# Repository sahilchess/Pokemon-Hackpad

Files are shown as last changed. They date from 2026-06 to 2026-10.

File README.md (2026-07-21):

# Pokemon Hackpad!
<!---
![picture of pokemon hackpad](assets/photo.png)
picture to come!
-->

[CAD](https://cad.onshape.com/documents/8d1a80880a531cce319d6767/w/a72820820093b362710dff01/e/ab70c80eedf68ce27917fcfd)

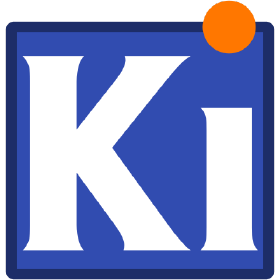
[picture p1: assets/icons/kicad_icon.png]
kicad
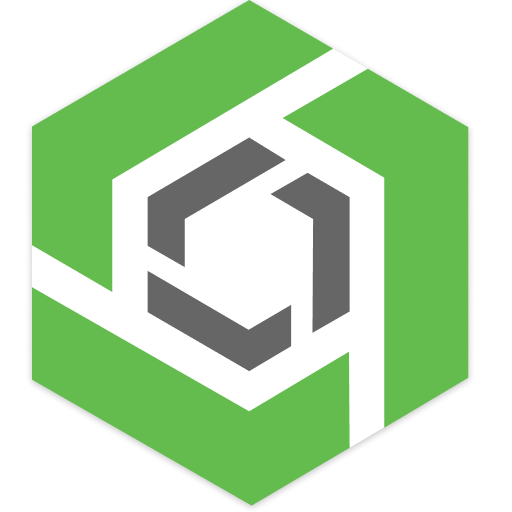
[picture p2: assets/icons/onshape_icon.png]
onshape
  things used (https://skillicons.dev)

Pokemon Hackpad is a 5 key macropad with a rotary switch/encoder, and 4 SK6812 MINI E RGB LEDs. It uses KMK/QMK(wip) firmware. I designed this as my own macropad through [hackpad](https://hackclub.hackpad.com), a Hack Club program where you learn to design your own macropad and get it for free

## Features:
- An EC11 rotary encoder, controls volume, click to mute
- 3 SK6812 MINI E RGB LEDs, swirl and static modes
- 5 Cherry MX style keys
- 128x32 OLED Screen
- Pokemon themed design

## CAD Model:
Here is the case, made in onshape. I used onshape because Fusion basically blew my computer up. 





## PCB
Here's the PCB, made in KiCad.




## Firmware Overview
This hackpad uses [KMK](https://github.com/KMKfw/kmk_firmware) firmware for everything.
- the rotary encoder changes volume, press to mute
- the 5 regular keys are copy, paste, undo, redo
- rgb leds swirl by default, static color available

## BOM (more elaborate BOM [here](http://github.com/sahilchess/Pokemon-Hackpad/blob/main/production/BOM.md)):
Here should be everything you need to make this amazing hackpad
- 5x Cherry MX Switches
- 5x DSA Keycaps
- 6x 1N4148 DO-35 Diodes
- 3x SK6812 MINI E RGB LEDs
- 1x EC11 Rotary Encoder
- 1x 0.91 inch OLED display
- 4x M3x16mm screws
- 4x M3x5mx4mm heatset inserts
- 1x XIAO RP2040



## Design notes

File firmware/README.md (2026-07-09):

# Firmware

This hackpad runs KMK firmware on the XIAO RP2040

## Files

main.py the whole firmware, matrix, encoder, rgb, and oled setup

## Pinout

col0 GP26, col1 GP27, col2 GP28
row0 GP3, row1 GP4
encoder a GP2, encoder b GP1, encoder click is wired into the matrix at row0 col2
rgb data GP29, 3x SK6812 MINI E leds
oled sda GP6, scl GP7, 0.91in 128x32 SSD1306

## Keymap

copy  paste  mute/encoder click
undo  select all  redo

encoder rotate changes volume, rgb boots into swirl mode, oled shows a static text screen

## Setup

install CircuitPython on the XIAO RP2040
copy the kmk library folder from kmk_firmware onto CIRCUITPY
copy main.py onto CIRCUITPY, it runs automatically on boot

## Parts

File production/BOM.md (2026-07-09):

# Pokemon Hackpad - Bill of Materials
Welcome to the **Bill of Materials (BOM)** for the Pokemon Hackpad.

| **Component** | **Qty** | **Notes** |
|---|---|---|
| **XIAO RP2040** | 1 | |
| **SK6812 Mini LEDs** | 4 | |
| **Rotary Encoder** | 1 | |
| **Cherry MX Switches** | 5 | |
| **Diodes** | 6 | |
| **OLED Display** | 1 | |

Others:

| **Component** | **Qty** | **Notes** |
|---|---|---|
| **1U Keycaps** | 5 | |
| **KMK Firmware** | 1 | |
| **PCB** | 5 | ordered from JLCPCB, Pokemon-Hackpad_Y29, $7.12 total, est arrival 2026-06-22 |

## Kit Provided

| **Part** | **Qty Provided** | **Qty Needed** |
|---|---|---|
| Seeed XIAO RP2040 microcontroller  | 1 | 1 |
| 1N4148 through hole diodes | 20 | 6 |
| MX style mechanical switches | 16 | 5 |
| EC11 rotary encoders (20mm D shaft)| 2 | 1 |
| SK6812 MINI E RGB LEDs | 20 | 4 |
| Blank DSA keycaps | 16 | 5 |
| M3x16mm screws | 6 | 4 |
| M3x5x4mm heatset inserts | 6 | 4 |
| OLED | 1 | 1 |

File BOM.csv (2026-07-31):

item | description | cost
hackpad kit | all parts needed to build hackpad | included
soldering iron grant | card grant to buy a soldering iron | $18
pcb grant | card grant to buy pcb | $15

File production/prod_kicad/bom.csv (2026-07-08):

Designator | Footprint | Quantity | Value | LCSC Part #
D1, D2, D3, D4, D5, D6 | D_DO-35_SOD27_P7.62mm_Horizontal | 6 | Diode
D10, D8, D9 | LED_SK6812MINI-E_3.2x2.8mm_P1.5mm_ReverseMount | 3 | SK6812MINI-E
J1 | SSD1306-0.91-OLED-4pin-128x32 | 1 | OLED_DISPLAY
S1, S2, S3, S4, S5 | SW_Cherry_MX_1.00u_PCB | 5 | Keyswitch
SW1 | RotaryEncoder_Alps_EC11E-Switch_Vertical_H20mm | 1 | RotaryEncoder_Switch
U1 | XIAO-Generic-Hybrid-14P-2.54-21X17.8MM | 1 | MOUDLE-SEEEDUINO-XIAO

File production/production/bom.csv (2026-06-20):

Designator | Footprint | Quantity | Value | LCSC Part #
D1, D2, D3, D4, D5, D6 | D_DO-35_SOD27_P7.62mm_Horizontal | 6 | Diode
D10, D7, D8, D9 | LED_SK6812MINI-E_3.2x2.8mm_P1.5mm_ReverseMount | 4 | SK6812MINI-E
S1, S2, S3, S4, S5 | SW_Cherry_MX_1.00u_PCB | 5 | Keyswitch
SW1 | RotaryEncoder_Alps_EC11E-Switch_Vertical_H20mm | 1 | RotaryEncoder_Switch
U1 | XIAO-Generic-Hybrid-14P-2.54-21X17.8MM | 1 | MOUDLE-SEEEDUINO-XIAO

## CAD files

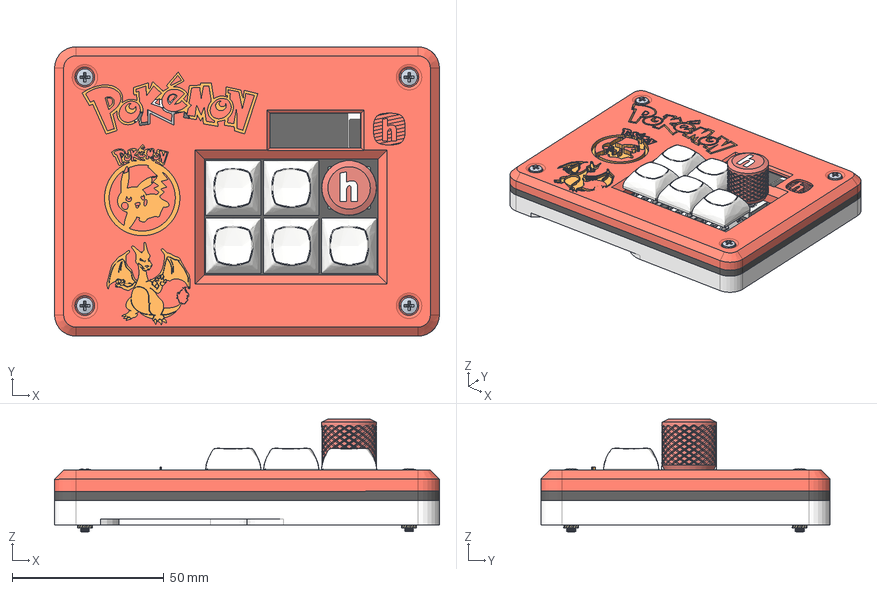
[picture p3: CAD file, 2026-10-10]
CAD/main.step
126.6 x 95.2 x 37.1 mm
Pokemon Hackpad-unsaved-export-4L2n7u_copper x 47
Pin2__Vaciado1 x 5
brep_1 x 4
DSA 1u v2__DSA 1u v2_1 x 5
H:1__Body1
Pin Header 4 x 1 TH 2.54mm Pitch:1__Твердое тело2
id55 x 4
00 Bottom Case
00 Top Case
Top__Redondeo7 x 5
Pin1__Redondeo1 x 5
Shield:1__Body1
Pokemon Hackpad-unsaved-export-4L2n7u_PCB
Bottom__Redondeo8 x 5
Pin Header 4 x 1 TH 2.54mm Pitch:1__Твердое тело7
Pieza5^Cherry MX__Cortar-Extruir2 x 5
Pulsador__Cortar-Extruir5 x 5
DSA 1u v2__DSA 1u v2
Pin Header 4 x 1 TH 2.54mm Pitch:1__Твердое тело3
Pin Header 4 x 1 TH 2.54mm Pitch:1__Твердое тело11
Pin Header 4 x 1 TH 2.54mm Pitch:1__Твердое тело8
Base:1__Body1
Pin Header 4 x 1 TH 2.54mm Pitch:1__Твердое тело1
CHAMFER9:1__Body1
MX Mount v1__MX Mount v1
Seeed Studio XIAO-ESP32-S3 (Sense):1__Body1
Pin Header 4 x 1 TH 2.54mm Pitch:1__Твердое тело4
00 Middle Case
Pin Header 4 x 1 TH 2.54mm Pitch:1__Твердое тело12
OLED_0.91_128x32:1__Твердое тело1
CUT-EXTRUDE5:1__Body1

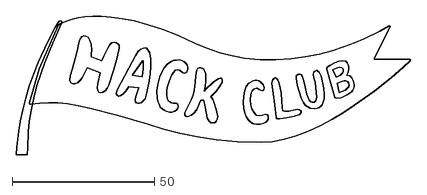
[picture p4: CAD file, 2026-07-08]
assets/flag-standalone.dxf
138.8 x 48.7

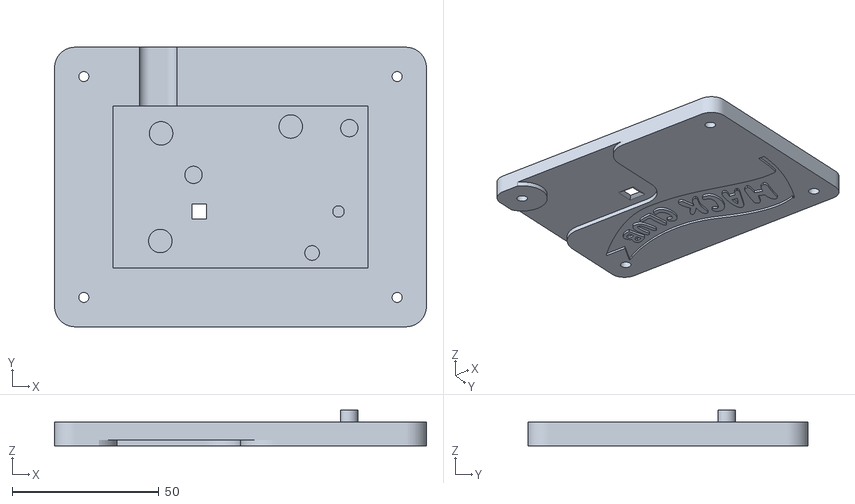
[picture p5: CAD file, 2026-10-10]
CAD/print this/bottom - white.stl
126.6 x 95.2 x 12.2

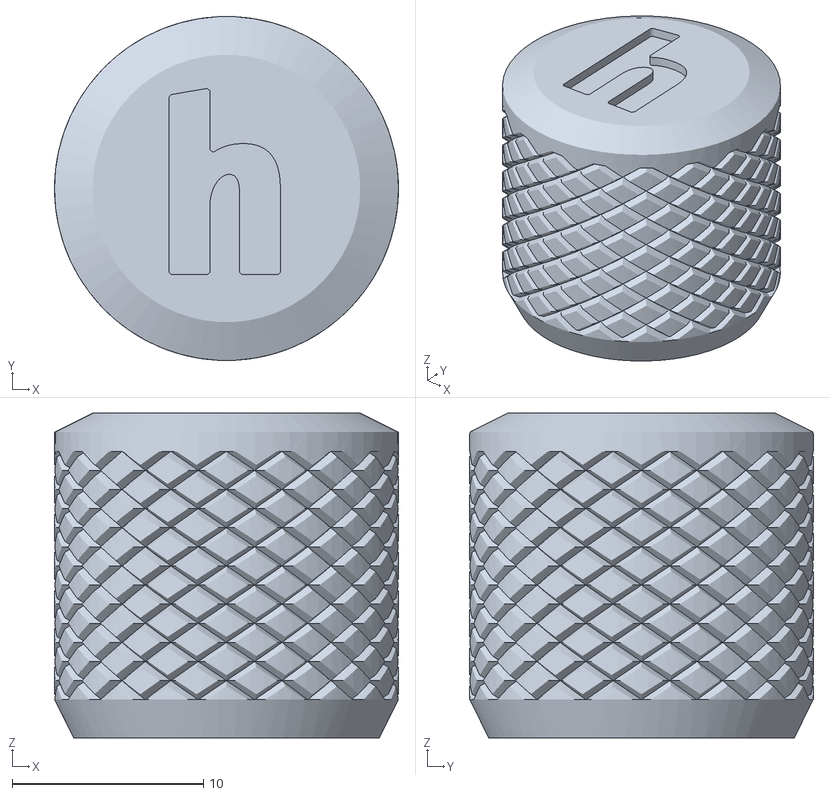
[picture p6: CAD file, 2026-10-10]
CAD/print this/knob/Knob-base - red.stl
18.0 x 18.0 x 17.0

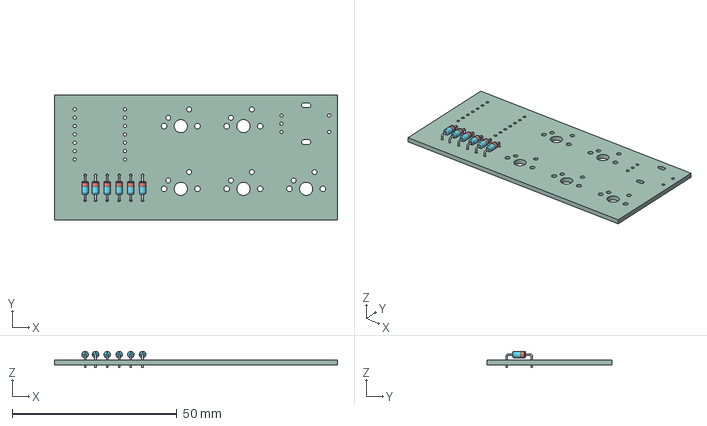
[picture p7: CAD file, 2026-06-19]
hardware/pcb/.step
86.0 x 38.1 x 5.01 mm
D_DO-35_SOD27_P7.62mm_Horizontal x 6
Pokemon Hackpad_PCB

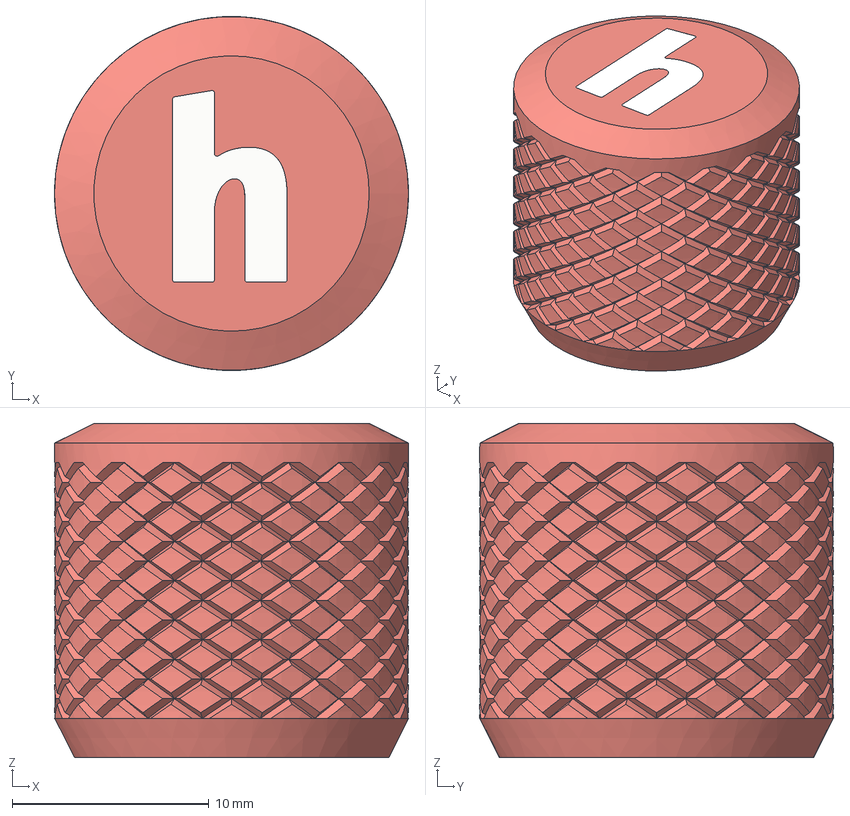
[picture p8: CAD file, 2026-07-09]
production/cad/knob/knob.step
18.0 x 18.0 x 17.0 mm
Base
H

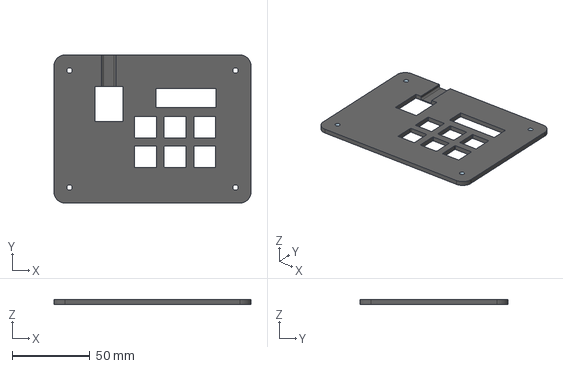
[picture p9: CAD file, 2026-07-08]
production/cad/Middle.step
126.6 x 95.2 x 3.00 mm

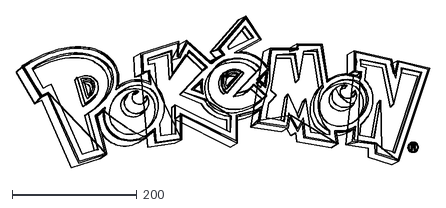
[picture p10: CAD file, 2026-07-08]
assets/pokemon_cleaned.dxf
661.4 x 242.6

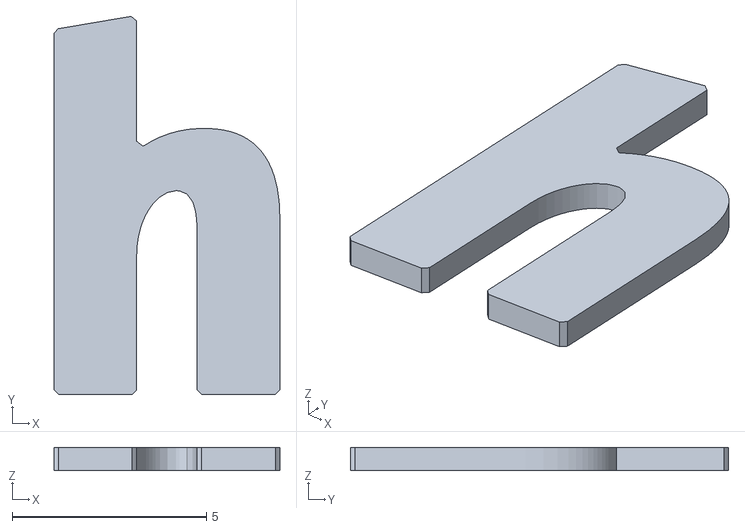
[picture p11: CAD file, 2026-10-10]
CAD/print this/knob/Knob-H - white.stl
5.82 x 9.74 x 0.6

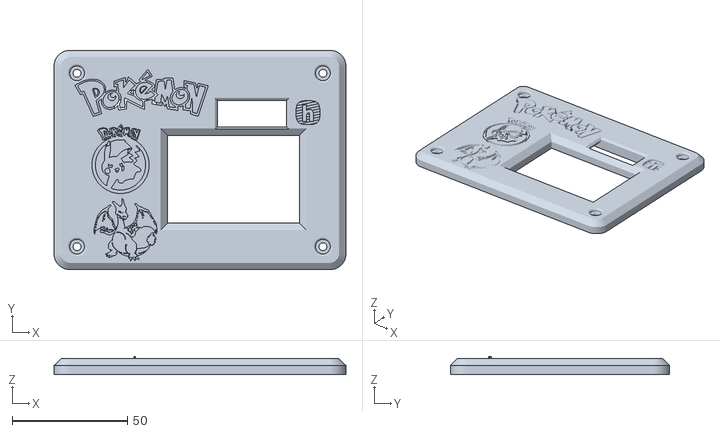
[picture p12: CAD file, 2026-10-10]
CAD/print this/top - red.stl
126.6 x 95.2 x 8.00

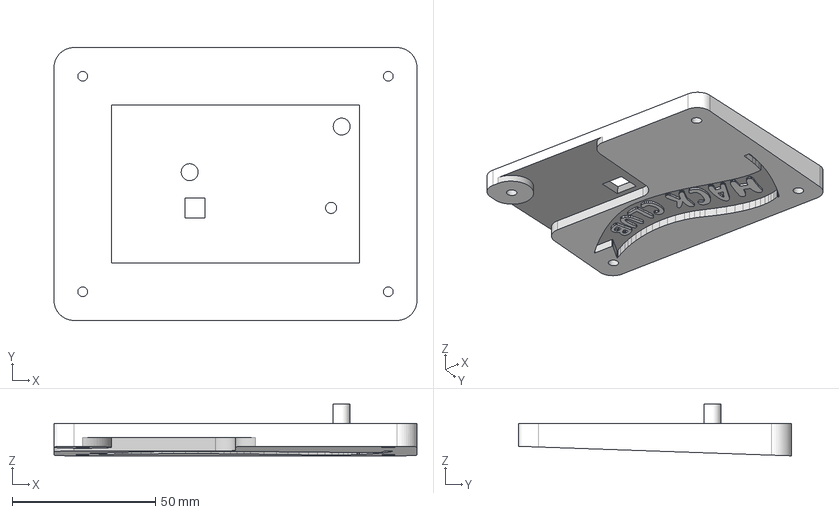
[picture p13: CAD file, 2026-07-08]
production/cad/Bottom.step
126.6 x 95.2 x 18.0 mm

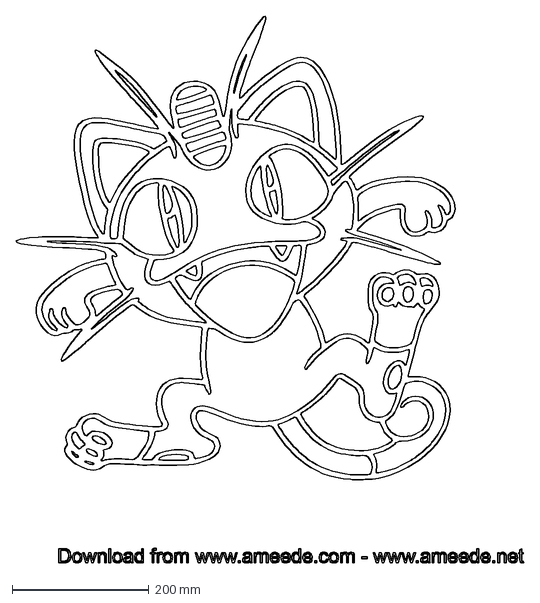
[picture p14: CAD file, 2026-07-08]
assets/meowth.dxf
740.9 x 798.7 mm

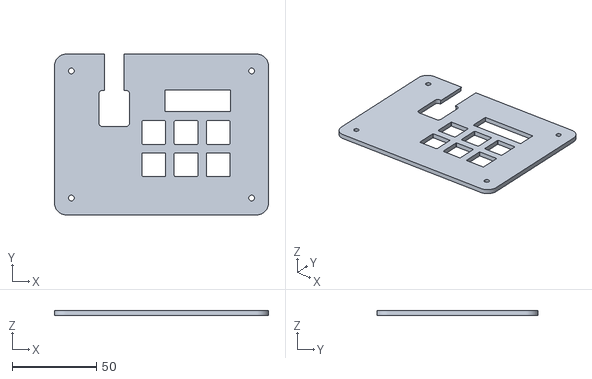
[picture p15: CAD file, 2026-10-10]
CAD/print this/middle - black.stl
126.6 x 95.2 x 3.00

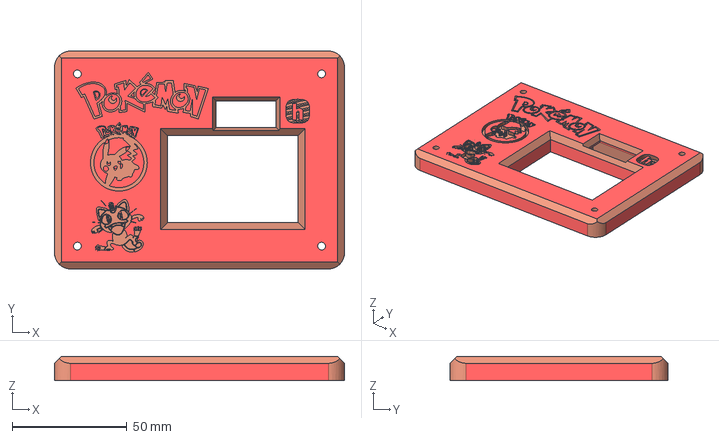
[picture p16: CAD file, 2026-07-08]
production/cad/Top.step
126.6 x 95.2 x 10.5 mm

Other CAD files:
assets/icon-progress-rounded.dxf
assets/graphics1.dxf
assets/plate.dxf

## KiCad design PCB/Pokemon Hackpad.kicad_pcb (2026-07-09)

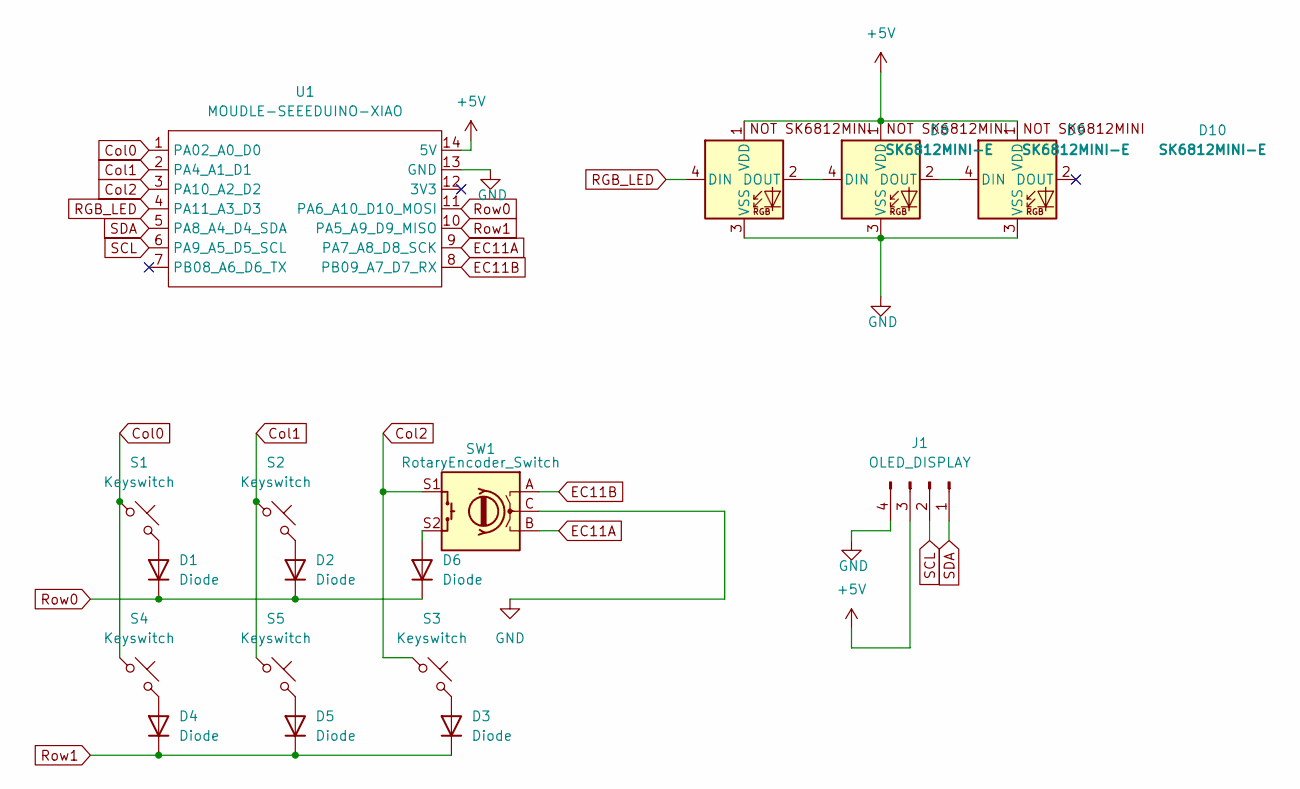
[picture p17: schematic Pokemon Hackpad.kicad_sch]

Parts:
D1, D2, D3, D4, D5, D6: Diode; D_DO-35_SOD27_P7.62mm_Horizontal
D8, D9, D10: SK6812MINI-E; LED_SK6812MINI-E_3.2x2.8mm_P1.5mm_ReverseMount
J1: OLED_DISPLAY; SSD1306-0.91-OLED-4pin-128x32
S1, S2, S3, S4, S5: Keyswitch; SW_Cherry_MX_1.00u_PCB
SW1: RotaryEncoder_Switch; RotaryEncoder_Alps_EC11E-Switch_Vertical_H20mm
U1: MOUDLE-SEEEDUINO-XIAO; XIAO-Generic-Hybrid-14P-2.54-21X17.8MM

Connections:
+5V: D8.1 (VDD), D9.1 (VDD), D10.1 (VDD), J1.3, U1.14 (5V)
Col0: S1.1, S4.1, U1.1 (PA02_A0_D0)
Col1: S2.1, S5.1, U1.2 (PA4_A1_D1)
Col2: S3.1, SW1.S1, U1.3 (PA10_A2_D2)
EC11A: SW1.B, U1.9 (PA7_A8_D8_SCK)
EC11B: SW1.A, U1.8 (PB09_A7_D7_RX)
GND: D8.3 (VSS), D9.3 (VSS), D10.3 (VSS), J1.4, SW1.C, U1.13 (GND)
unnamed: D1.2 (A), S1.2
unnamed: D2.2 (A), S2.2
unnamed: D3.2 (A), S3.2
unnamed: D4.2 (A), S4.2
unnamed: D5.2 (A), S5.2
unnamed: D6.2 (A), SW1.S2
unnamed: D8.2 (DOUT), D9.4 (DIN)
unnamed: D9.2 (DOUT), D10.4 (DIN)
RGB_LED: D8.4 (DIN), U1.4 (PA11_A3_D3)
Row0: D1.1 (K), D2.1 (K), D6.1 (K), U1.11 (PA6_A10_D10_MOSI)
Row1: D3.1 (K), D4.1 (K), D5.1 (K), U1.10 (PA5_A9_D9_MISO)
SCL: J1.2, U1.6 (PA9_A5_D5_SCL)
SDA: J1.1, U1.5 (PA8_A4_D4_SDA)

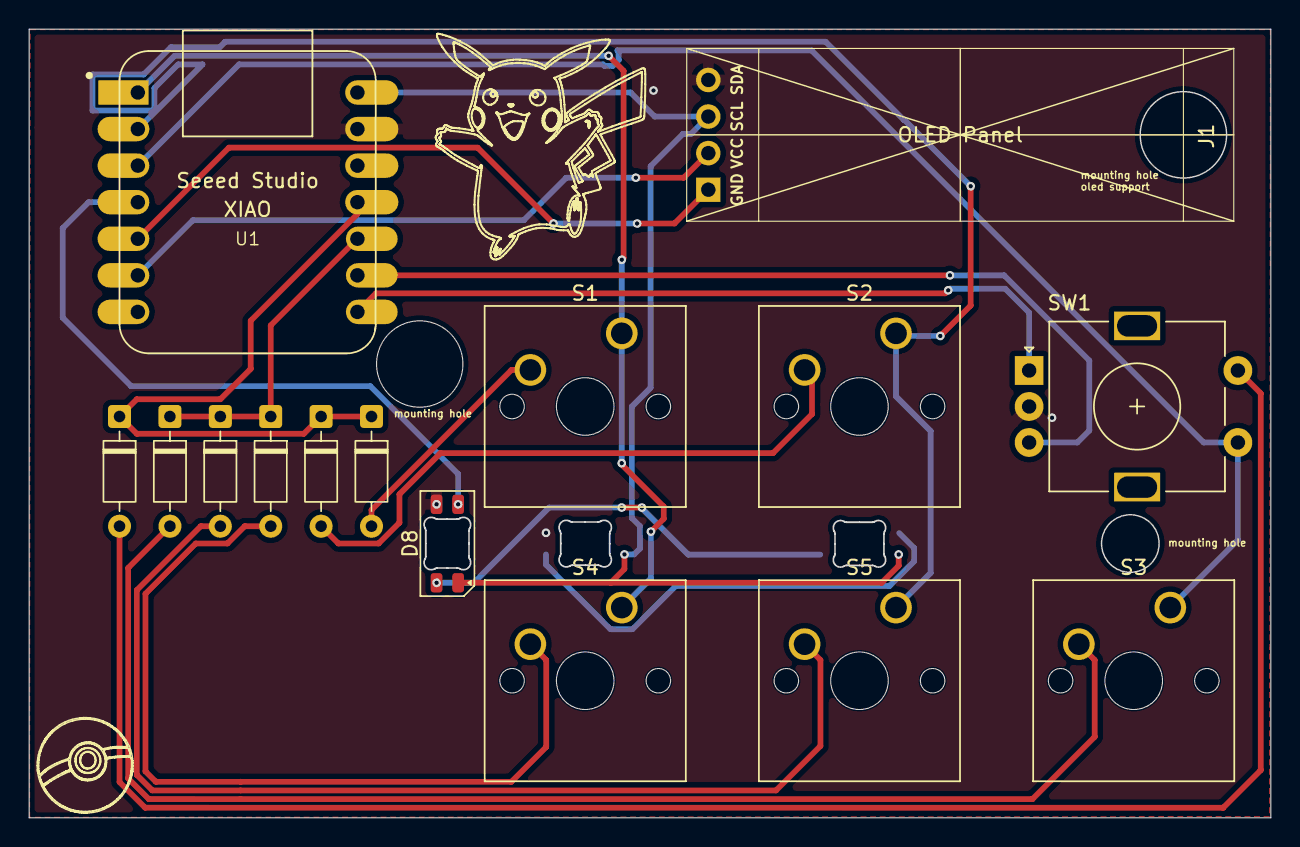
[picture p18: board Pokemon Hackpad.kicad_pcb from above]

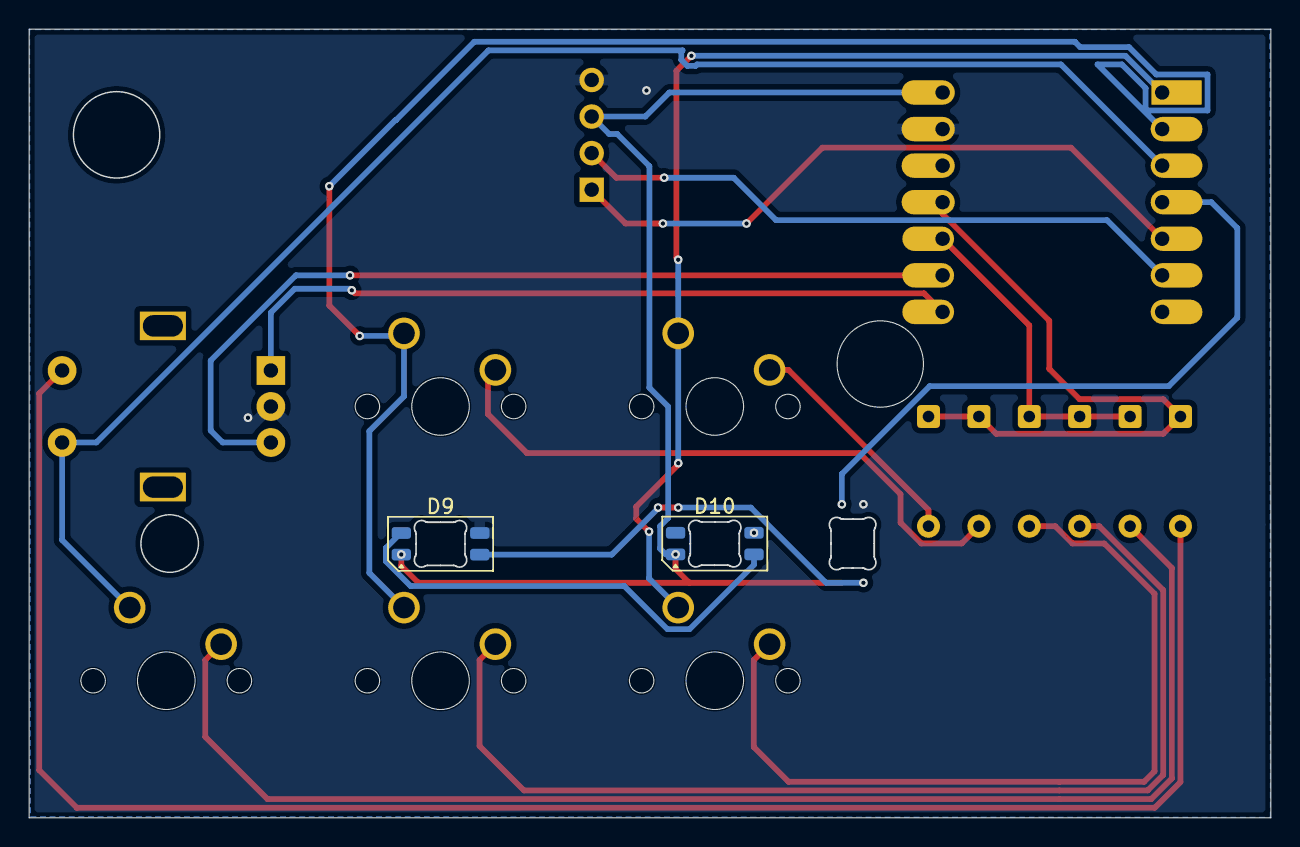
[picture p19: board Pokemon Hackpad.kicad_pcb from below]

Board: 2 copper layers, 86.2 x 54.8 mm, 17 parts (2 on the bottom side), 20 nets.

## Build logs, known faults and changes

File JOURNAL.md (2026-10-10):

---
title: "Pokemon Hackpad"
github: "[repo here](https://github.com/sahilchess/Pokemon-hackpad)"
description: "This is a hackpad I designed for stardance (never gonna do hw for stardance again) and spent abt 40 hours on. now the pieces are a bit mid and I am redesigning to make the parts fit better."
created_at: "2026-09-27"
# [first](https://hackatime.hackclub.com/my/projects/Pokemon%20Hackpad) [second](https://hackatime.hackclub.com/my/projects/Pokemon-Hackpad) 
hackatime_projects: "[phantom_one](https://hackatime.hackclub.com/my/projects/Pokemon%20Hackpad%20Phantom)"
---

<!--
# month #th: <journal entry title!>

<the actual journal content! what you did, some interesting findings, etc.>

<at least 1 picture of where you're currently at! the more the better>

hackatime: [time](https://lapse.hackclub.com/timelapse/)

**Total time spent: Xhr**

-->

# September 27th: started redesigning

i got through what i found wrong with my design
- pcb had no clearance for the keys sticking out
- oled had a very tight fit
- screw holes were too long
- slant was kinda useless
- usb plug couldn't fit in the small hole
- overall body was too thick
- meowth design did not print correctly
- diodes wont have any clearance
- mcu wont have clearance

[mistakes](https://cdn.hackclub.com/01a10314-450c-7a1b-875c-d4254d2d08e1/mistakes.mp4)

i learned how to use assemblies :skulk: after all this time and they should assist me in making this the 2nd best (to orpheuspad) macropad to rule the lands.

hackatime: [36m](https://lapse.hackclub.com/timelapse/ouGhkufe5J1e)

**Total time spent: .6hr**

# September 28th - October 3rd: redesign v1?

I fixed all the problems listed above and got it printed from a friend tommorow to see the improvements:

[fixed](https://cdn.hackclub.com/01a103b2-725a-7d83-801a-0d33e54465bd/fixed.mp4)

hackatime: [1h 33m](https://lapse.hackclub.com/timelapse/dk_SIRY0y4f5) | [37m](https://lapse.hackclub.com/timelapse/RPRlJr80LP2-) | [18m](https://lapse.hackclub.com/timelapse/jQyD46O-yBGQ) | [55m](https://lapse.hackclub.com/timelapse/8HcNnHTQOTB4) | [1h](https://lapse.hackclub.com/timelapse/cA6_7CbDKFfI) | [22m](https://lapse.hackclub.com/timelapse/_WCaXIK6F4nG) | [17m](https://lapse.hackclub.com/timelapse/jOp1lLwHnrQe) | [1h 7m](https://lapse.hackclub.com/timelapse/skEoo9PBqjy1) | [12m](https://lapse.hackclub.com/timelapse/T2KOj3at_5ce)

**Total time spent: 6.35hr**

# October 3rd: soldering

soldered the rotary, oled, diodes, and mcu

[here](https://lookout.hackclub.com/api/media/033fe245-e08f-4a49-ac98-abe75bee5e8c/video.mp4)

hackatime: [56m](https://lapse.hackclub.com/timelapse/lEt-0jJpvme7)

**Total time spent: .93hr**

# October 4 - October 10: finishing touches

reordered my pcb cuz the oled pins were reversed.
did some finishing touches for my case and sent a quote in #printing-legion. also i just saw that hyper-chroma cool things and i hope this project is good enough! 

hackatime: [39m](https://lapse.hackclub.com/timelapse/BxYMIa21RD5-) | [28m](https://lapse.hackclub.com/timelapse/hy41wROVyg84)

**Total time spent: 1.1hr**

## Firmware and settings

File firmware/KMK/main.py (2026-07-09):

import board
import busio
import displayio

from kmk.kmk_keyboard import KMKKeyboard
from kmk.keys import KC
from kmk.matrix import DiodeOrientation
from kmk.modules.encoder import EncoderHandler
from kmk.extensions.rgb import RGB, AnimationModes
from kmk.extensions.display import Display, TextEntry
from kmk.extensions.display.ssd1306 import SSD1306

keyboard = KMKKeyboard()

keyboard.col_pins = (board.GP26, board.GP27, board.GP28)
keyboard.row_pins = (board.GP3, board.GP4)
keyboard.diode_orientation = DiodeOrientation.COL2ROW

encoder_handler = EncoderHandler()
encoder_handler.pins = ((board.GP2, board.GP1, None),)
encoder_handler.map = ((KC.VOLU, KC.VOLD),)
keyboard.modules.append(encoder_handler)

rgb = RGB(
    pixel_pin=board.GP29,
    num_pixels=3,
    animation_mode=AnimationModes.SWIRL,
    hue_default=0,
    sat_default=100,
    val_default=100,
)
keyboard.extensions.append(rgb)

# 0.91in 128x32 ssd1306 oled over i2c on gp6 sda gp7 scl
displayio.release_displays()
i2c_bus = busio.I2C(board.GP7, board.GP6)
driver = SSD1306(i2c=i2c_bus, device_address=0x3C)
display = Display(
    entries=[TextEntry(text='pokemon hackpad', x=0, y=0)],
    width=128,
    height=32,
    driver=driver,
)
keyboard.extensions.append(display)

keyboard.keymap = [
    [
        KC.LCTL(KC.C), KC.LCTL(KC.V), KC.MUTE,
        KC.LCTL(KC.Y), KC.LSFT(KC.LCTL(KC.A)), KC.LCTL(KC.Z),
    ]
]

if __name__ == '__main__':
    keyboard.go()

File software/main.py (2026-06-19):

import board
from kmk.kmk_keyboard import KMKKeyboard
from kmk.keys import KC
from kmk.scanners import DiodeOrientation
from kmk.modules.encoder import EncoderHandler
from kmk.extensions.rgb import RGB, AnimationModes

keyboard = KMKKeyboard()

keyboard.col_pins = (board.GP26, board.GP27, board.GP28)
keyboard.row_pins = (board.GP3, board.GP4)
keyboard.diode_orientation = DiodeOrientation.COL2ROW

encoder_handler = EncoderHandler()
encoder_handler.pins = ((board.GP2, board.GP7, None),)
keyboard.modules.append(encoder_handler)

rgb = RGB(
    pixel_pin=board.GP29,
    num_pixels=4,
    val_limit=100,
    hue_default=0,
    sat_default=100,
    val_default=100,
    animation_mode=AnimationModes.SWIRL,
)
keyboard.extensions.append(rgb)

# solid color instead of wave, swap animation_mode above to AnimationModes.STATIC
# rgb = RGB(
#     pixel_pin=board.GP29,
#     num_pixels=4,
#     val_limit=100,
#     hue_default=0,
#     sat_default=100,
#     val_default=100,
#     animation_mode=AnimationModes.STATIC,
# )
# keyboard.extensions.append(rgb)

keyboard.keymap = [
    [
        KC.NO, KC.NO, KC.MUTE,
        KC.NO, KC.NO, KC.NO,
    ]
]

encoder_handler.map = [
    ((KC.VOLU, KC.VOLD, KC.NO),),
]

if __name__ == '__main__':
    keyboard.go()


"""
col0, D0, GP26
col1, D1, GP27
col2, D2, GP28
row0, D10, GP3
row1, D9, GP4
ec11a, D8, GP2
ec11b, D5, GP7
rgb_led, D3, GP29

"""

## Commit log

2026-06-19 added rgb leds
    [Pokemon Hackpad.kicad_pcb, Pokemon Hackpad.kicad_sch, full_case.step]
2026-06-20 submission file structure
    [.step, Bottom.step, Pokemon Hackpad.kicad_pcb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]
2026-06-20 submission files
    [Pokemon Hackpad.kicad_pcb]
2026-07-08 submission things
    [.step, Bottom.step, Full Case.step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]
2026-07-08 Update README with new images for CAD and PCB
    Added additional images for CAD and PCB sections.
2026-07-09 Refactor encoder pins and add SSD1306 display
2026-07-09 Add OLED Display to BOM and update components list
2026-07-09 cad stuff
    [Bottom.step, Middle.step, Pokemon Hackpad.kicad_pcb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]
2026-07-31 Add BOM.csv with item details and costs
    [BOM.csv]
2026-10-10 finsihing touches
    [Full Case.step, Full w components.step, Knob-H - white.stl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]
